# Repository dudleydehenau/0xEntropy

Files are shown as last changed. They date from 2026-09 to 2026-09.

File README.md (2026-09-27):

<h1 align="center">0xEntropy</h1>

<p align="center">
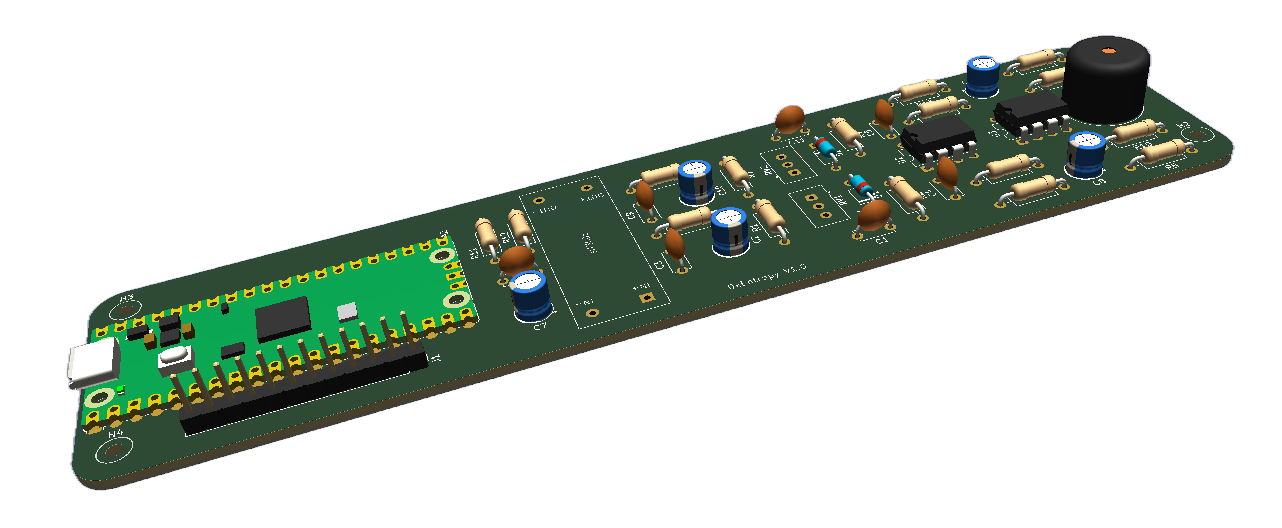
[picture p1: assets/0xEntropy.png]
PCB 3D Render
  
</p>

<p align="center">
  <em>Compact, open-source, USB-powered True Random Number Generator (TRNG) based on Zener diode avalanche breakdown noise and powered by an RP2040.</em>
</p>

---

## Overview

**0xEntropy** is a standalone hardware entropy generator. It harnesses the physical phenomenon of avalanche breakdown in a Zener diode to capture non-deterministic quantum noise, amplifies it, digitizes it at high speed using the Raspberry Pi Pico PIO state machines, and applies real-time SHA-256 cryptographic whitening.

The system features an onboard touchscreen interface, continuous health monitoring, and streams random data over USB.

---

## Features

- **Pure Physical Source**: Avalanche breakdown noise from a reverse-biased 12V Zener diode, filtered and amplified (MCP6002).
- **Filtered Virtual Ground ($V_{REF} = 2.5\text{V}$)**: Strict isolation against USB power rail noise and ripples.
- **Hardware Sampling (PIO)**: High-speed, jitter-free capture offloaded from the CPU.
- **Dual-Core Architecture (RP2040)**:
  - **Core 0**: Touchscreen LCD interface (ultra-lightweight 1-bit bitmap rendering engine), statistics processing, and alerts.
  - **Core 1**: Raw bit acquisition, real-time statistical health tests, and SHA-256 post-processing.
- **Live Monitoring**: Real-time Shannon entropy calculation and physical source health supervision.
- **100% Plug & Play**: Powered and queried via a standard USB port.

---

## Hardware & Schematics (KiCad)

The PCB isolates the sensitive analog front-end (Zener, op-amp, comparator) from the digital domain (RP2040, screen).

### Schematic
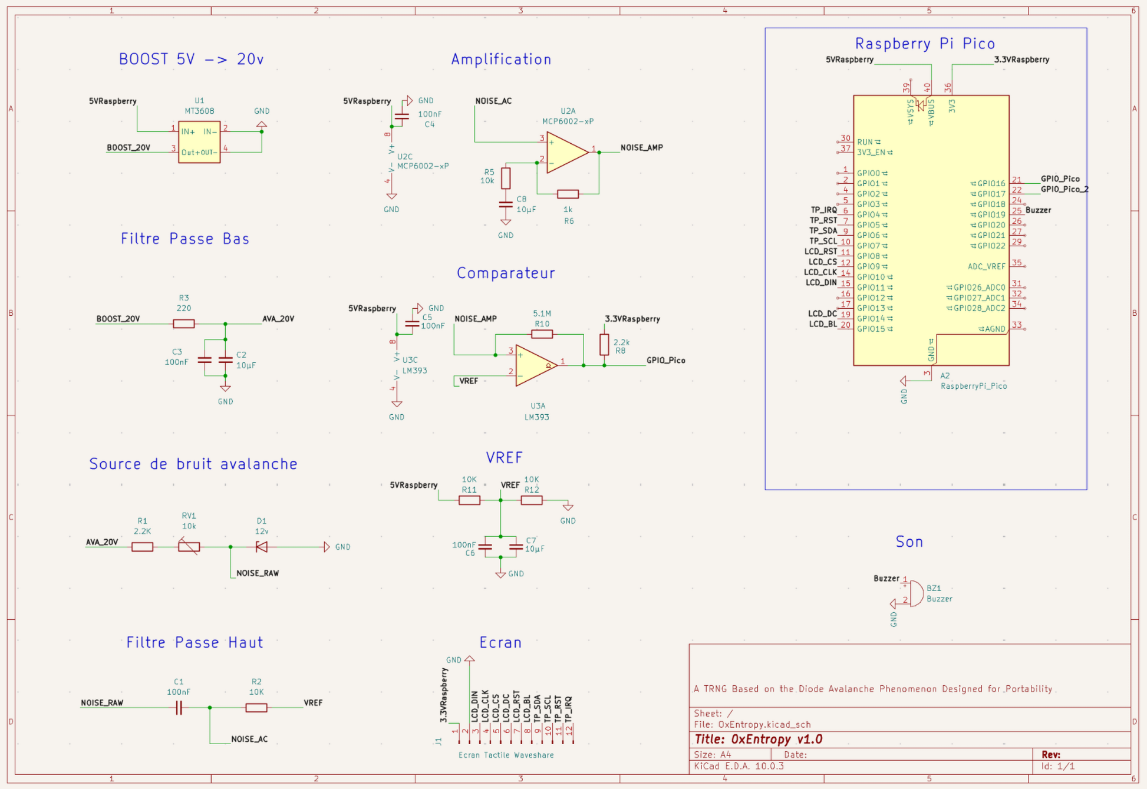
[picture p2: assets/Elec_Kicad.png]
KiCad Schematic


### PCB Layout
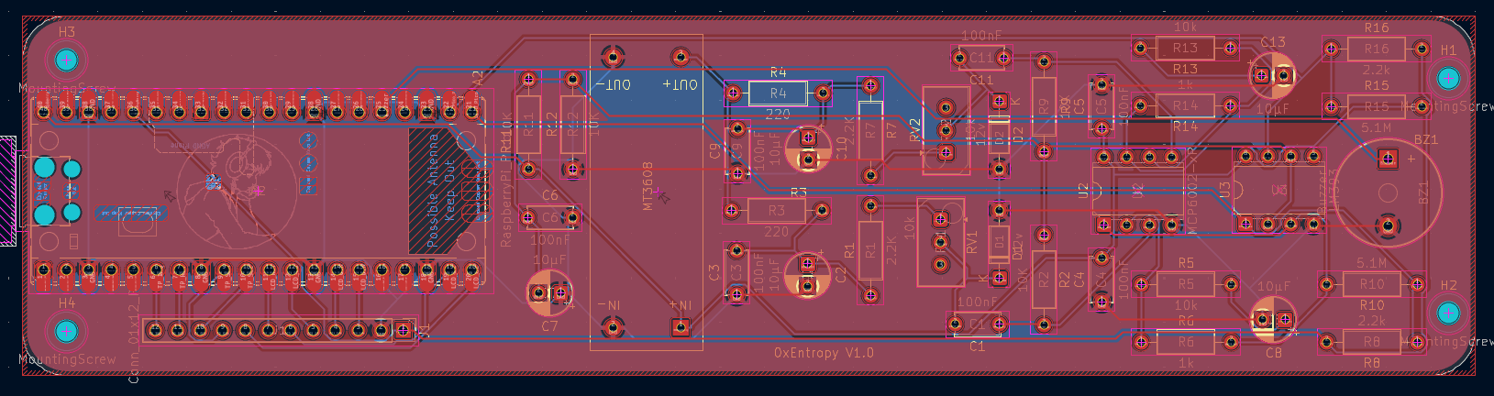
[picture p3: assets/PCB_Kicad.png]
KiCad PCB Routing


---

## Enclosure & 3D Design

A custom 3D enclosure was designed to house the main board, the touchscreen display, and provide access to the micro-USB port.

<table>
  <tr>
    <th width="50%" align="center">3D Model</th>
    <th width="50%" align="center">Assembled Prototype</th>
  </tr>
  <tr>
    <td align="center">
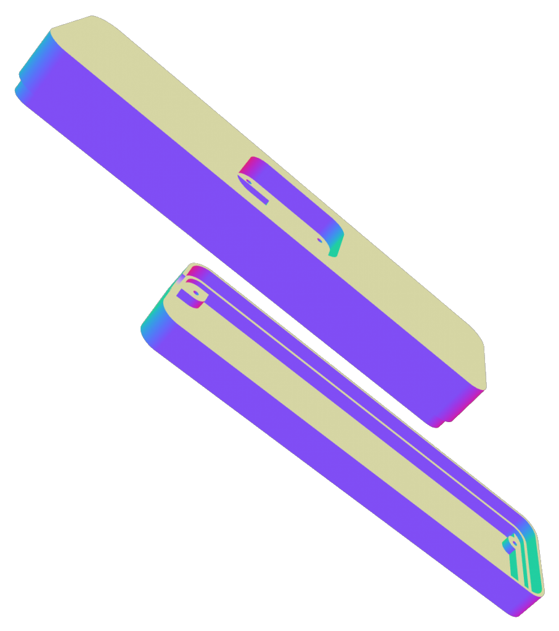
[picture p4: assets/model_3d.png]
3D Model
      
    </td>
    <td align="center">
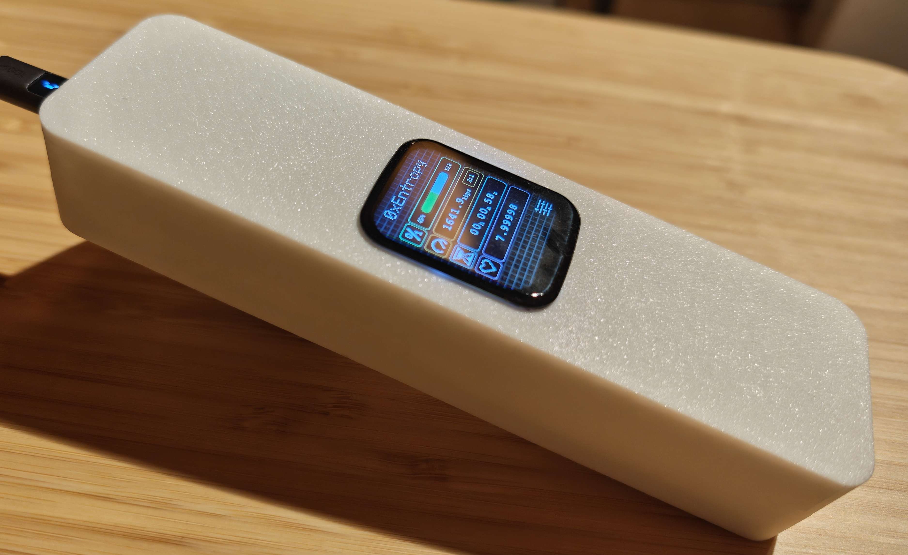
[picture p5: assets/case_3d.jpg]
Enclosure Photo
      
    </td>
  </tr>
</table>

<p align="center">
  3D Printing Timelapse
  <br>
  <em>Enclosure 3D printing timelapse</em>
</p>

*(F3D / STEP source files are available in the `/file3D` directory)*

---

## Firmware Structure

The firmware is written in **C/C++** using the Pico SDK:

- `firmware/0xEntropy.c`: Main entry point, orchestration, and core loop.
- `firmware/Entropy/`: Physical signal sampling and entropy generation routines.
- `firmware/Health/`: Continuous health monitoring (failure detection and drift detection).
- `firmware/Stats/`: Real-time statistical computations on bitstreams.
- `firmware/UI/`: Display drivers and user interface logic.

<p align="center">
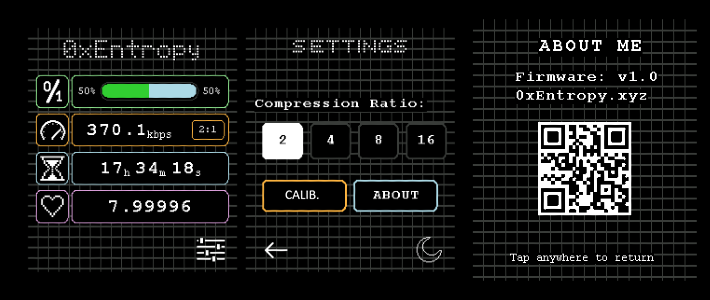
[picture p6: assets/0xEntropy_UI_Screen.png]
UI Screen
  
  <br>
  <em>Simulated values</em>
</p>

---

## Full Prototype Overview

Overall view of the assembled hardware: the operational PCB connected to the touchscreen display.

<p align="center">
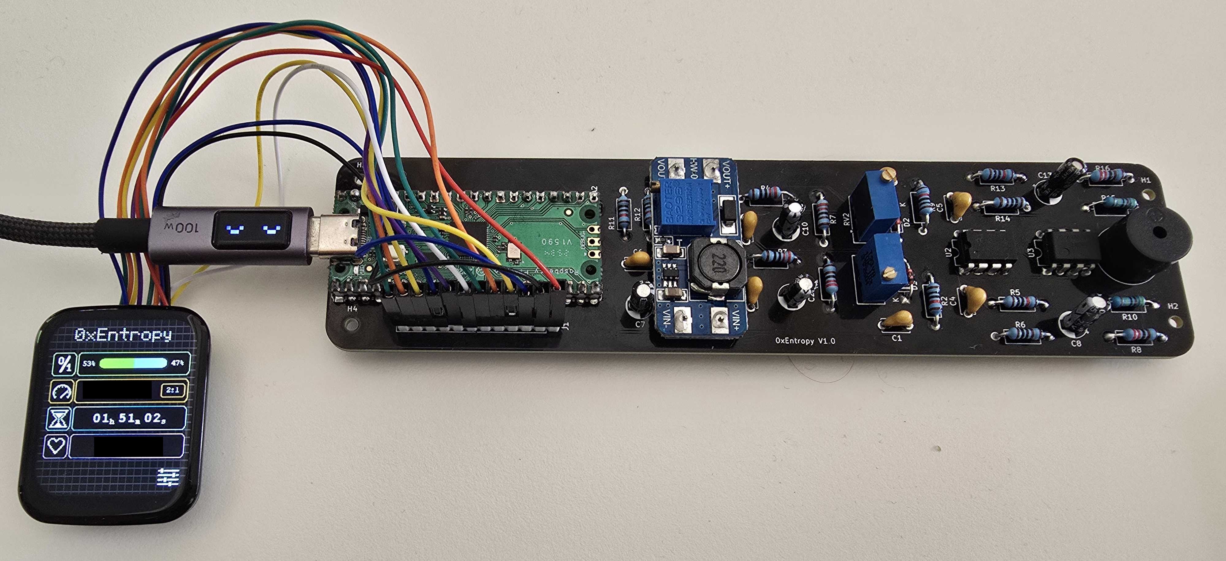
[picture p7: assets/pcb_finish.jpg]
Complete 0xEntropy Prototype
  
  <br>
  <em>Final 0xEntropy board assembled and connected to its touchscreen display</em>
</p>

---

## Quick Start

### 1. Flash the RP2040
1. Download the latest `0xEntropy.uf2` binary from the [Releases](../../releases).
2. Hold down the **BOOTSEL** button on the Raspberry Pi Pico and plug it into your computer via USB.
3. Drag and drop the `.uf2` file onto the mounted USB storage volume.

### 2. Stream Random Bytes

The Pico emulates a standard USB CDC serial port.

#### Option A: Using the Python Script (Recommended / Cross-platform)
Handles real-time throughput monitoring, automatic resume on disconnect, and works on Windows, Linux, and macOS:

```bash
# Dependency
pip install pyserial

# Stream data (e.g., capture 100 MB)
python collect.py -p COM4 -s 100000000 -o random.bin
```

#### Option B: Direct Command Line (Linux / macOS)
```bash
# Quick capture of 1 MB
head -c 1M /dev/ttyACM0 > random.bin
```

---

### 3. Verify Entropy Quality

Quick distribution analysis using the standard `ent` tool:

```bash
ent random.bin
```

Comprehensive statistical test battery with **Dieharder**:

```bash
# Run the full test suite (-a) on a binary stream (-g 201)
dieharder -a -g 201 -f random.bin
```

---

## Performance & Validation

The generator has been rigorously tested and validated for statistical randomness at scale.

- **Observed Throughput**: **~1,300 kbps** (~162 KB/s) continuous stream over USB CDC.
- **Post-Processing**: SHA-256 cryptographic whitening. Default 2:1 compression ratio (512:256 bits), user-selectable on-screen (4:1, 8:1, 16:1).

---

### 1. `ent` Test (10 GB Dataset)

Raw distribution analysis performed on a continuous **10 GB** dataset (`10,000,000,000 bytes`):

```text
Entropy = 8.000000 bits per byte.

Optimum compression would reduce the size
of this 10000000000 byte file by 0 percent.

Chi square distribution for 10000000000 samples is 279.96, and randomly
would exceed this value 13.56 percent of the times.

Arithmetic mean value of data bytes is 127.5013 (127.5 = random).
Monte Carlo value for Pi is 3.141522385 (error 0.00 percent).
Serial correlation coefficient is -0.000013 (totally uncorrelated = 0.0).
```

---

### 2. Dieharder Test Suite (10 GB Dataset)

Full results from the **Dieharder v3.31.1** test battery executed against a **10 GB** stream (SHA-256 2:1 ratio):

<details>

<summary><b>Click to view all 86 detailed test results (Dieharder)</b></summary>

| Test Name | ntuple | tsamples | psamples | p-value | Assessment |
| :--- | :---: | :---: | :---: | :---: | :---: |
| `diehard_birthdays` | 0 | 100 | 100 | 0.39466437 | **PASSED** |
| `diehard_operm5` | 0 | 1 000 000 | 100 | 0.07592355 | **PASSED** |
| `diehard_rank_32x32` | 0 | 40 000 | 100 | 0.59062810 | **PASSED** |
| `diehard_rank_6x8` | 0 | 100 000 | 100 | 0.95475163 | **PASSED** |
| `diehard_bitstream` | 0 | 2 097 152 | 100 | 0.40506079 | **PASSED** |
| `diehard_opso` | 0 | 2 097 152 | 100 | 0.88837531 | **PASSED** |
| `diehard_oqso` | 0 | 2 097 152 | 100 | 0.69125958 | **PASSED** |
| `diehard_dna` | 0 | 2 097 152 | 100 | 0.69906629 | **PASSED** |
| `diehard_count_1s_str` | 0 | 256 000 | 100 | 0.39737472 | **PASSED** |
| `diehard_count_1s_byt` | 0 | 256 000 | 100 | 0.92060347 | **PASSED** |
| `diehard_parking_lot` | 0 | 12 000 | 100 | 0.43926798 | **PASSED** |
| `diehard_2dsphere` | 2 | 8 000 | 100 | 0.92344609 | **PASSED** |
| `diehard_3dsphere` | 3 | 4 000 | 100 | 0.96173291 | **PASSED** |
| `diehard_squeeze` | 0 | 100 000 | 100 | 0.79221232 | **PASSED** |
| `diehard_sums` | 0 | 100 | 100 | 0.55542507 | **PASSED** |
| `diehard_runs` | 0 | 100 000 | 100 | 0.13786658 | **PASSED** |
| `diehard_runs` | 0 | 100 000 | 100 | 0.17085449 | **PASSED** |
| `diehard_craps` | 0 | 200 000 | 100 | 0.67687026 | **PASSED** |
| `diehard_craps` | 0 | 200 000 | 100 | 0.91082777 | **PASSED** |
| `marsaglia_tsang_gcd` | 0 | 10 000 000 | 100 | 0.93839213 | **PASSED** |
| `marsaglia_tsang_gcd` | 0 | 10 000 000 | 100 | 0.84764647 | **PASSED** |
| `sts_monobit` | 1 | 100 000 | 100 | 0.28551441 | **PASSED** |
| `sts_runs` | 2 | 100 000 | 100 | 0.29973049 | **PASSED** |
| `sts_serial` | 1 | 100 000 | 100 | 0.45563392 | **PASSED** |
| `sts_serial` | 2 | 100 000 | 100 | 0.14689616 | **PASSED** |
| `sts_serial` | 3 | 100 000 | 100 | 0.16976266 | **PASSED** |
| `sts_serial` | 3 | 100 000 | 100 | 0.58643956 | **PASSED** |
| `sts_serial` | 4 | 100 000 | 100 | 0.62041623 | **PASSED** |
| `sts_serial` | 4 | 100 000 | 100 | 0.93374301 | **PASSED** |
| `sts_serial` | 5 | 100 000 | 100 | 0.42325503 | **PASSED** |
| `sts_serial` | 5 | 100 000 | 100 | 0.96197560 | **PASSED** |
| `sts_serial` | 6 | 100 000 | 100 | 0.21788455 | **PASSED** |
| `sts_serial` | 6 | 100 000 | 100 | 0.69535327 | **PASSED** |
| `sts_serial` | 7 | 100 000 | 100 | 0.03066406 | **PASSED** |
| `sts_serial` | 7 | 100 000 | 100 | 0.01328619 | **PASSED** |
| `sts_serial` | 8 | 100 000 | 100 | 0.62365992 | **PASSED** |
| `sts_serial` | 8 | 100 000 | 100 | 0.28004021 | **PASSED** |
| `sts_serial` | 9 | 100 000 | 100 | 0.90096448 | **PASSED** |
| `sts_serial` | 9 | 100 000 | 100 | 0.97761790 | **PASSED** |
| `sts_serial` | 10 | 100 000 | 100 | 0.51356615 | **PASSED** |
| `sts_serial` | 10 | 100 000 | 100 | 0.64523823 | **PASSED** |
| `sts_serial` | 11 | 100 000 | 100 | 0.93859732 | **PASSED** |
| `sts_serial` | 11 | 100 000 | 100 | 0.32514183 | **PASSED** |
| `sts_serial` | 12 | 100 000 | 100 | 0.19453278 | **PASSED** |
| `sts_serial` | 12 | 100 000 | 100 | 0.35736285 | **PASSED** |
| `sts_serial` | 13 | 100 000 | 100 | 0.41024144 | **PASSED** |
| `sts_serial` | 13 | 100 000 | 100 | 0.52009147 | **PASSED** |
| `sts_serial` | 14 | 100 000 | 100 | 0.63356596 | **PASSED** |
| `sts_serial` | 14 | 100 000 | 100 | 0.05597814 | **PASSED** |
| `sts_serial` | 15 | 100 000 | 100 | 0.44014124 | **PASSED** |
| `sts_serial` | 15 | 100 000 | 100 | 0.17108281 | **PASSED** |
| `sts_serial` | 16 | 100 000 | 100 | 0.83506756 | **PASSED** |
| `sts_serial` | 16 | 100 000 | 100 | 0.92781694 | **PASSED** |
| `rgb_bitdist` | 1 | 100 000 | 100 | 0.50215495 | **PASSED** |
| `rgb_bitdist` | 2 | 100 000 | 100 | 0.67467770 | **PASSED** |
| `rgb_bitdist` | 3 | 100 000 | 100 | 0.68604339 | **PASSED** |
| `rgb_bitdist` | 4 | 100 000 | 100 | 0.63639093 | **PASSED** |
| `rgb_bitdist` | 5 | 100 000 | 100 | 0.00711522 | **PASSED** |
| `rgb_bitdist` | 6 | 100 000 | 100 | 0.03642615 | **PASSED** |
| `rgb_bitdist` | 7 | 100 000 | 100 | 0.54886931 | **PASSED** |
| `rgb_bitdist` | 8 | 100 000 | 100 | 0.94844778 | **PASSED** |
| `rgb_bitdist` | 9 | 100 000 | 100 | 0.80804374 | **PASSED** |
| `rgb_bitdist` | 10 | 100 000 | 100 | 0.76694934 | **PASSED** |
| `rgb_bitdist` | 11 | 100 000 | 100 | 0.55405954 | **PASSED** |
| `rgb_bitdist` | 12 | 100 000 | 100 | 0.79849495 | **PASSED** |
| `rgb_minimum_distance` | 2 | 10 000 | 1000 | 0.38755637 | **PASSED** |
| `rgb_minimum_distance` | 3 | 10 000 | 1000 | 0.93853771 | **PASSED** |
| `rgb_minimum_distance` | 4 | 10 000 | 1000 | 0.63970846 | **PASSED** |
| `rgb_minimum_distance` | 5 | 10 000 | 1000 | 0.33087978 | **PASSED** |
| `rgb_permutations` | 2 | 100 000 | 100 | 0.80472843 | **PASSED** |
| `rgb_permutations` | 3 | 100 000 | 100 | 0.80939095 | **PASSED** |
| `rgb_permutations` | 4 | 100 000 | 100 | 0.64196966 | **PASSED** |
| `rgb_permutations` | 5 | 100 000 | 100 | 0.97396760 | **PASSED** |
| `rgb_lagged_sum` | 0 | 1 000 000 | 100 | 0.29546209 | **PASSED** |
| `rgb_lagged_sum` | 1 | 1 000 000 | 100 | 0.10736047 | **PASSED** |
| `rgb_lagged_sum` | 2 | 1 000 000 | 100 | 0.90786168 | **PASSED** |
| `rgb_lagged_sum` | 3 | 1 000 000 | 100 | 0.03800803 | **PASSED** |
| `rgb_lagged_sum` | 4 | 1 000 000 | 100 | 0.69745767 | **PASSED** |
| `rgb_lagged_sum` | 5 | 1 000 000 | 100 | 0.30052203 | **PASSED** |
| `rgb_lagged_sum` | 6 | 1 000 000 | 100 | 0.81286624 | **PASSED** |
| `rgb_lagged_sum` | 7 | 1 000 000 | 100 | 0.79490517 | **PASSED** |
| `rgb_lagged_sum` | 8 | 1 000 000 | 100 | 0.85376675 | **PASSED** |
| `rgb_lagged_sum` | 9 | 1 000 000 | 100 | 0.46383055 | **PASSED** |
| `rgb_lagged_sum` | 10 | 1 000 000 | 100 | 0.63063661 | **PASSED** |
| `rgb_lagged_sum` | 11 | 1 000 000 | 100 | 0.39341615 | **PASSED** |
| `rgb_lagged_sum` | 12 | 1 000 000 | 100 | 0.21353291 | **PASSED** |
| `rgb_lagged_sum` | 13 | 1 000 000 | 100 | 0.73964502 | **PASSED** |
| `rgb_lagged_sum` | 14 | 1 000 000 | 100 | 0.76922594 | **PASSED** |
| `rgb_lagged_sum` | 15 | 1 000 000 | 100 | 0.55600967 | **PASSED** |
| `rgb_lagged_sum` | 16 | 1 000 000 | 100 | 0.59271918 | **PASSED** |
| `rgb_lagged_sum` | 17 | 1 000 000 | 100 | 0.90342589 | **PASSED** |
| `rgb_lagged_sum` | 18 | 1 000 000 | 100 | 0.59641374 | **PASSED** |
| `rgb_lagged_sum` | 19 | 1 000 000 | 100 | 0.59765640 | **PASSED** |
| `rgb_lagged_sum` | 20 | 1 000 000 | 100 | 0.52991615 | **PASSED** |
| `rgb_lagged_sum` | 21 | 1 000 000 | 100 | 0.44300317 | **PASSED** |
| `rgb_lagged_sum` | 22 | 1 000 000 | 100 | 0.94796060 | **PASSED** |
| `rgb_lagged_sum` | 23 | 1 000 000 | 100 | 0.20987094 | **PASSED** |
| `rgb_lagged_sum` | 24 | 1 000 000 | 100 | 0.36604221 | **PASSED** |
| `rgb_lagged_sum` | 25 | 1 000 000 | 100 | 0.28560285 | **PASSED** |
| `rgb_lagged_sum` | 26 | 1 000 000 | 100 | 0.52958989 | **PASSED** |
| `rgb_lagged_sum` | 27 | 1 000 000 | 100 | 0.17134459 | **PASSED** |
| `rgb_lagged_sum` | 28 | 1 000 000 | 100 | 0.99634800 | *WEAK* |
| `rgb_lagged_sum` | 29 | 1 000 000 | 100 | 0.36655513 | **PASSED** |
| `rgb_lagged_sum` | 30 | 1 000 000 | 100 | 0.16353244 | **PASSED** |
| `rgb_lagged_sum` | 31 | 1 000 000 | 100 | 0.36323221 | **PASSED** |
| `rgb_lagged_sum` | 32 | 1 000 000 | 100 | 0.67537924 | **PASSED** |
| `rgb_kstest_test` | 0 | 10 000 | 1000 | 0.60363864 | **PASSED** |
| `dab_bytedistrib` | 0 | 51 200 000 | 1 | 0.70763534 | **PASSED** |
| `dab_dct` | 256 | 50 000 | 1 | 0.18425080 | **PASSED** |
| `dab_filltree` | 32 | 15 000 000 | 1 | 0.80178758 | **PASSED** |
| `dab_filltree` | 32 | 15 000 000 | 1 | 0.26571865 | **PASSED** |
| `dab_filltree2` | 0 | 5 000 000 | 1 | 0.69465598 | **PASSED** |
| `dab_filltree2` | 1 | 5 000 000 | 1 | 0.71074721 | **PASSED** |
| `dab_monobit2` | 12 | 65 000 000 | 1 | 0.57586976 | **PASSED** |

</details>

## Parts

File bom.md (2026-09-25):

# Bill of Materials (BOM) — OxEntropy

| Réf. Schéma | Qté | Valeur / Désignation | Fabricant | Réf. Fabricant / Commande | Empreinte / Package |
| :--- | :---: | :--- | :--- | :--- | :--- |
| **A2** | 1 | Raspberry Pi Pico | Raspberry Pi | Raspberry Pi Pico | Module Pico THT |
| **BZ1** | 1 | Buzzer 12x9.5 RM7.6 | — | Buzzer THT | Buzzer_12x9.5RM7.6 |
| **C1, C3–C6, C9, C11** | 7 | 100nF | — | Céramique multicouche | C_Disc_D5.0mm_P5.00mm |
| **C2, C7, C8, C10, C13** | 5 | 10µF | — | Électrolytique Radial | CP_Radial_D5.0mm_P2.50mm |
| **D1, D2** | 2 | Diode Zener 12V | Nexperia | BZX79-C12 | DO-35 (SOD27) THT |
| **J1** | 1 | Connecteur 1x12 broches | — | Pin Header 2.54mm | PinHeader_1x12_P2.54mm_Vertical |
| **R1, R7, R8, R16** | 4 | 2.2kΩ | — | Résistance traversante 1/4W | R_Axial_DIN0207_P10.16mm |
| **R2, R5, R9, R11–R13** | 6 | 10kΩ | — | Résistance traversante 1/4W | R_Axial_DIN0207_P10.16mm |
| **R3, R4** | 2 | 220Ω | — | Résistance traversante 1/4W | R_Axial_DIN0207_P10.16mm |
| **R6, R14** | 2 | 1kΩ | — | Résistance traversante 1/4W | R_Axial_DIN0207_P10.16mm |
| **R10, R15** | 2 | 5.1MΩ | — | Résistance traversante 1/4W | R_Axial_DIN0207_P10.16mm |
| **RV1, RV2** | 2 | Potentiomètre 10kΩ | Vishay | T93YA103K | Vishay T93YA Vertical |
| **U1** | 1 | MT3608 (Module Step-Up) | TECNOIOT / Generic | MT3608 | Module Perso:MT3608 |
| **U2** | 1 | MCP6002-E/P (Ampli Op) | Microchip | MCP6002-E/P | DIP-8 (W7.62mm) |
| **U3** | 1 | LM393P (Comparateur) | Texas Instruments | LM393P | DIP-8 (W7.62mm) |

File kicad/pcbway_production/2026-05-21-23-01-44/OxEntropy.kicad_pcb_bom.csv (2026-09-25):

Designator | Quantity | Value | Footprint | Package | MPN | DNP | Mount_Type | Description | KiLib_Generator
A2 | 1 | RaspberryPi_Pico | RaspberryPi_Pico_Common_Unspecified |  |  |  | tht | Versatile and inexpensive microcontroller module powered by RP2040 dual-core Arm Cortex-M0+ processor up to 133 MHz, 264kB SRAM, 2MB QSPI flash; also supports Raspberry Pi Pico 2
BZ1 | 1 | Buzzer | Buzzer_12x9.5RM7.6 |  |  |  | tht | Buzzer, polarized
C1, C11, C3, C4, C5, C6, C9 | 7 | 100nF | C_Disc_D5.0mm_W2.5mm_P5.00mm |  |  |  | tht | Unpolarized capacitor, small symbol | capacitor/THT/other
C10, C13, C2, C7, C8 | 5 | 10µF | CP_Radial_D5.0mm_P2.50mm |  |  |  | tht | Unpolarized capacitor, small symbol | capacitor/THT/other
D1, D2 | 2 | 12v | D_DO-35_SOD27_P7.62mm_Horizontal |  |  |  | tht | Zener diode | diode/THT
J1 | 1 | Conn_01x12_Pin | PinHeader_1x12_P2.54mm_Vertical |  |  |  | tht | Generic connector, single row, 01x12, script generated | connector/pin_header_socket
R1, R7 | 2 | 2.2K | R_Axial_DIN0207_L6.3mm_D2.5mm_P10.16mm_Horizontal |  |  |  | tht | Resistor | resistor/THT
R10, R15 | 2 | 5.1M | R_Axial_DIN0207_L6.3mm_D2.5mm_P10.16mm_Horizontal |  |  |  | tht | Resistor | resistor/THT
R11, R12, R2, R9 | 4 | 10K | R_Axial_DIN0207_L6.3mm_D2.5mm_P10.16mm_Horizontal |  |  |  | tht | Resistor | resistor/THT
R13, R5 | 2 | 10k | R_Axial_DIN0207_L6.3mm_D2.5mm_P10.16mm_Horizontal |  |  |  | tht | Resistor | resistor/THT
R14, R6 | 2 | 1k | R_Axial_DIN0207_L6.3mm_D2.5mm_P10.16mm_Horizontal |  |  |  | tht | Resistor | resistor/THT
R16, R8 | 2 | 2.2k | R_Axial_DIN0207_L6.3mm_D2.5mm_P10.16mm_Horizontal |  |  |  | tht | Resistor | resistor/THT
R3, R4 | 2 | 220 | R_Axial_DIN0207_L6.3mm_D2.5mm_P10.16mm_Horizontal |  |  |  | tht | Resistor | resistor/THT
RV1, RV2 | 2 | 10k | Potentiometer_Vishay_T93YA_Vertical |  |  |  | tht | Trimmable resistor (preset resistor)
U1 | 1 | MT3608 | MT3608 |  |  |  | smt | High Efficiency 1.2MHz 2A Step Up Converter, 2-24V Vin, 28V Vout, 4A current limit, 1.2MHz, SOT23-6
U2 | 1 | MCP6002-xP | DIP-8_W7.62mm |  |  |  | tht | 1MHz, Low-Power Op Amp, DIP-8 | package/DIP/legacy
U3 | 1 | LM393 | DIP-8_W7.62mm |  |  |  | tht | Low-Power, Low-Offset Voltage, Dual Comparators, DIP-8/SOIC-8/TO-99-8 | package/DIP/legacy

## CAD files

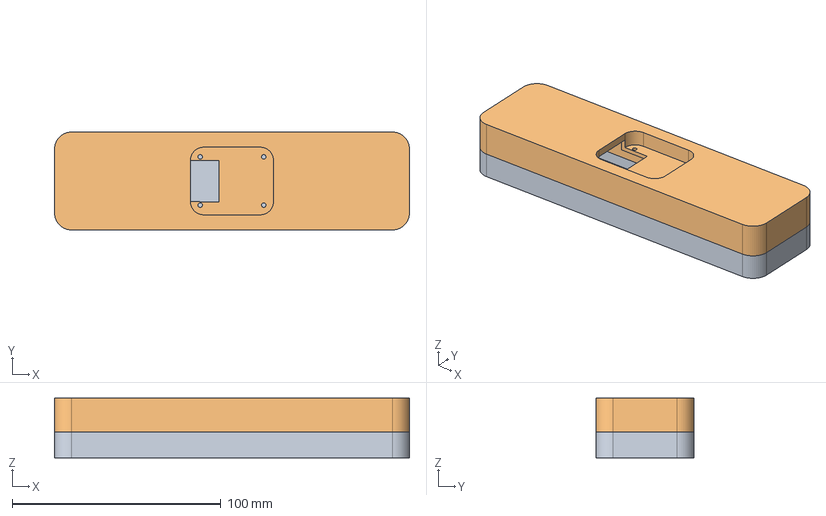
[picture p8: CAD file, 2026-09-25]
file3D/3D0xEntropyFinal.step
169.9 x 46.9 x 28.5 mm

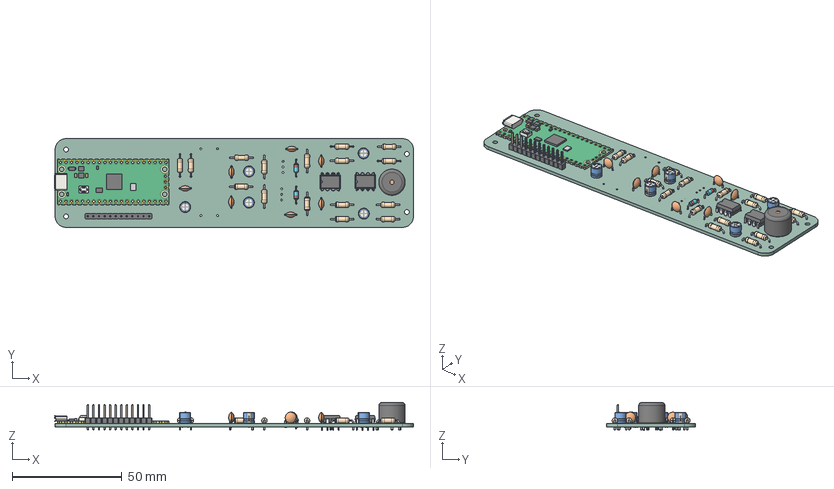
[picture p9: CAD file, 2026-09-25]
kicad/.step
163.8 x 40.5 x 12.8 mm
R_Axial_DIN0207_L63mm_D25mm_P1016mm_Horizontal x 16
CP_Radial_D50mm_P250mm x 5
DIP-8_W7.62mm x 2
RaspberryPi_Pico_Module_KiCad
C_Disc_D50mm_W25mm_P500mm x 7
PinHeader_1x12_P254mm_Vertical
D_DO-35_SOD27_P7.62mm_Horizontal x 2
Buzzer_12x95RM76
OxEntropy_PCB

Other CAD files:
file3D/3D0xEntropyFinal.f3d

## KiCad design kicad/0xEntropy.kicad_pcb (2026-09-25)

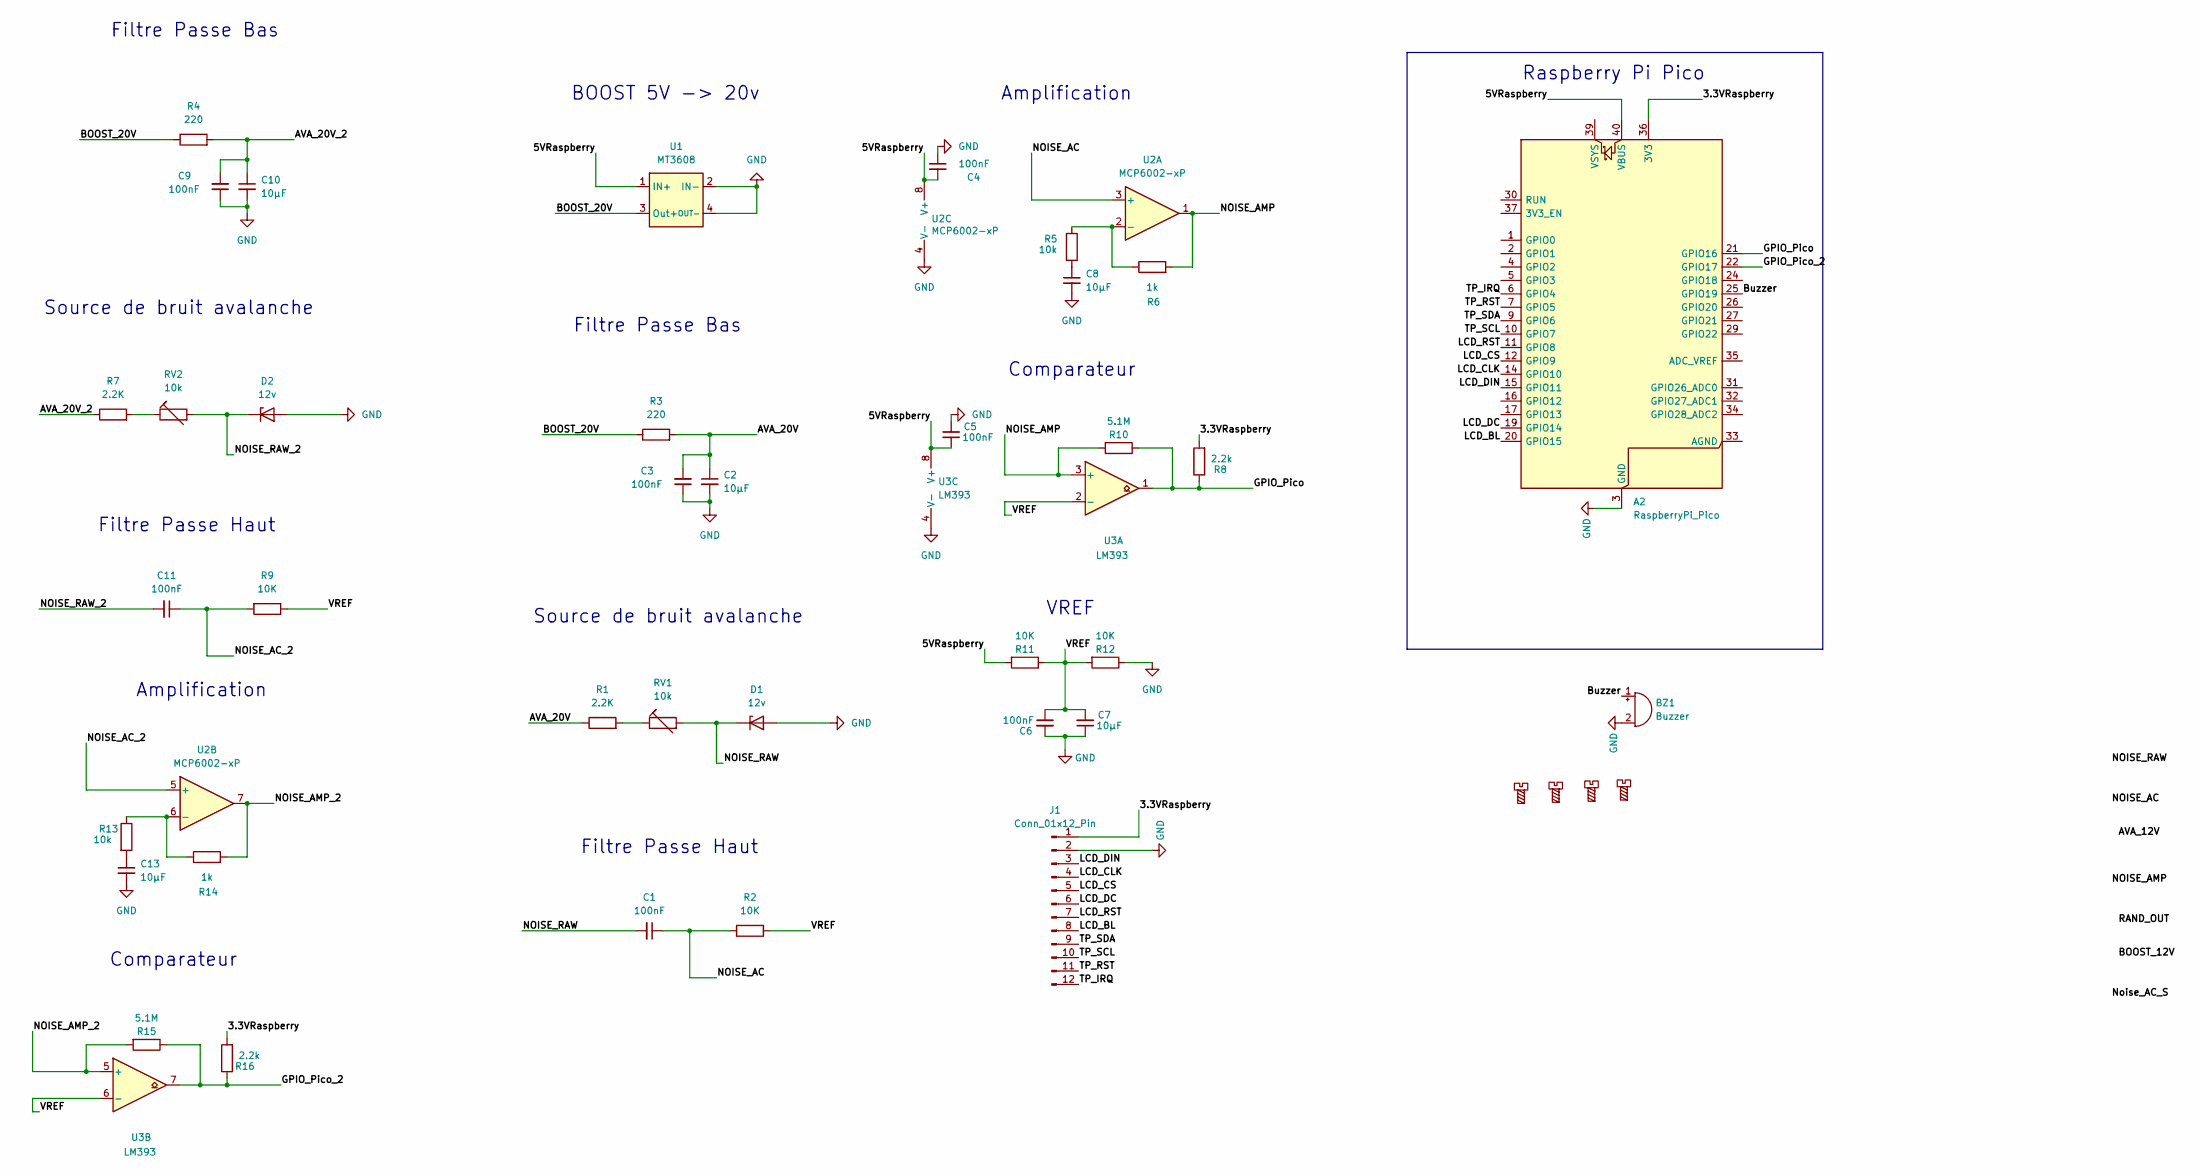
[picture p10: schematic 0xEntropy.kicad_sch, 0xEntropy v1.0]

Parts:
A2: RaspberryPi_Pico; RaspberryPi_Pico_Common_Unspecified
BZ1: Buzzer; Buzzer_12x9.5RM7.6
C1, C3, C4, C5, C6, C9, C11: 100nF; C_Disc_D5.0mm_W2.5mm_P5.00mm
C2, C7, C8, C10, C13: 10µF; CP_Radial_D5.0mm_P2.50mm
D1, D2: 12v; D_DO-35_SOD27_P7.62mm_Horizontal
H1, H2, H3, H4: MountingScrew; MountingHole_2.2mm_M2
J1: Conn_01x12_Pin; PinHeader_1x12_P2.54mm_Vertical
R1, R7: 2.2K; R_Axial_DIN0207_L6.3mm_D2.5mm_P10.16mm_Horizontal
R2, R9, R11, R12: 10K; R_Axial_DIN0207_L6.3mm_D2.5mm_P10.16mm_Horizontal
R3, R4: 220; R_Axial_DIN0207_L6.3mm_D2.5mm_P10.16mm_Horizontal
R5, R13: 10k; R_Axial_DIN0207_L6.3mm_D2.5mm_P10.16mm_Horizontal
R6, R14: 1k; R_Axial_DIN0207_L6.3mm_D2.5mm_P10.16mm_Horizontal
R8, R16: 2.2k; R_Axial_DIN0207_L6.3mm_D2.5mm_P10.16mm_Horizontal
R10, R15: 5.1M; R_Axial_DIN0207_L6.3mm_D2.5mm_P10.16mm_Horizontal
RV1, RV2: 10k; Potentiometer_Vishay_T93YA_Vertical
U1: MT3608
U2: MCP6002-xP; DIP-8_W7.62mm
U3: LM393; DIP-8_W7.62mm

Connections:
/3.3VRaspberry: A2.36 (3V3), J1.1, R8.2, R16.2
/5VRaspberry: A2.40 (VBUS), C4.2, C5.1, R11.2, U1.1 (IN+), U2.8 (V+), U3.8 (V+)
/AVA_20V: C2.1, C3.2, R1.1, R3.2
/AVA_20V_2: C9.2, C10.1, R4.2, R7.1
/BOOST_20V: R3.1, R4.1, U1.3 (Out+)
/Buzzer: A2.25 (GPIO19), BZ1.1 (+)
/GPIO_Pico: A2.21 (GPIO16), R8.1, R10.1, U3.1
/GPIO_Pico_2: A2.22 (GPIO17), R15.1, R16.1, U3.7
/LCD_BL: A2.20 (GPIO15), J1.8
/LCD_CLK: A2.14 (GPIO10), J1.4
/LCD_CS: A2.12 (GPIO9), J1.5
/LCD_DC: A2.19 (GPIO14), J1.6
/LCD_DIN: A2.15 (GPIO11), J1.3
/LCD_RST: A2.11 (GPIO8), J1.7
/NOISE_AC: C1.1, R2.2, U2.3 (+)
/NOISE_AC_2: C11.1, R9.2, U2.5 (+)
/NOISE_AMP: R6.2, R10.2, U2.1, U3.3 (+)
/NOISE_AMP_2: R14.2, R15.2, U2.7, U3.5 (+)
/NOISE_RAW: C1.2, D1.1 (K), RV1.2
/NOISE_RAW_2: C11.2, D2.1 (K), RV2.2
/TP_IRQ: A2.6 (GPIO4), J1.12
/TP_RST: A2.7 (GPIO5), J1.11
/TP_SCL: A2.10 (GPIO7), J1.10
/TP_SDA: A2.9 (GPIO6), J1.9
/VREF: C6.1, C7.2, R2.1, R9.1, R11.1, R12.2, U3.2 (-), U3.6 (-)
GND: A2.3 (GND), A2.8 (GND), A2.13 (GND), A2.18 (GND), A2.23 (GND), A2.28 (GND), A2.38 (GND), BZ1.2 (-), C2.2, C3.1, C4.1, C5.2, C6.2, C7.1, C8.2, C9.1, C10.2, C13.2, D1.2 (A), D2.2 (A), J1.2, R12.1, U1.2 (IN-), U1.4 (OUT-), U2.4 (V-), U3.4 (V-)
unnamed: C8.1, R5.2
unnamed: C13.1, R13.2
unnamed: R1.2, RV1.1
unnamed: R7.2, RV2.1
unnamed: R5.1, R6.1, U2.2 (-)
unnamed: R13.1, R14.1, U2.6 (-)

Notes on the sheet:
Amplification
Source de bruit avalanche
Filtre Passe Bas
Comparateur
Filtre Passe Haut
VREF
BOOST 5V -> 20v
Raspberry Pi Pico

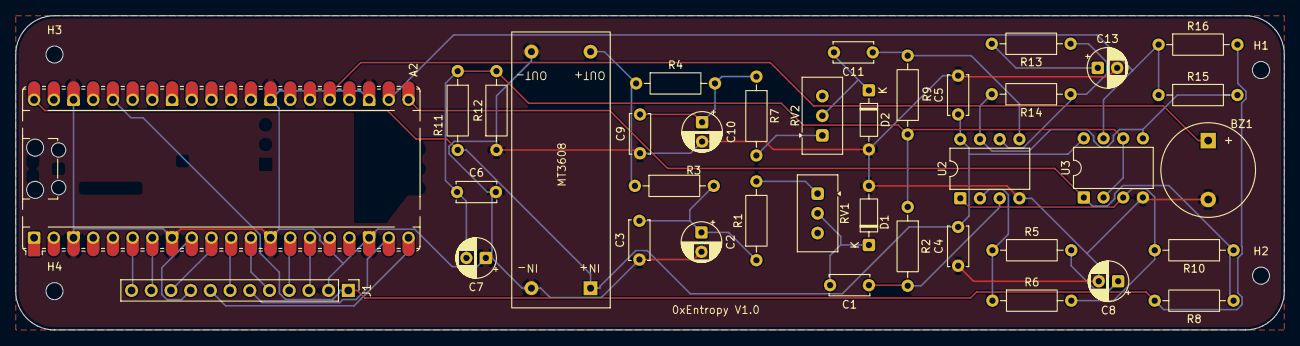
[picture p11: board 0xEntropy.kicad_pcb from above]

Board: 2 copper layers, 163.5 x 40.5 mm, 42 parts (0 on the bottom side), 32 nets.

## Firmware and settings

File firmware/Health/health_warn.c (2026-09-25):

#include "health_warn.h"

// faut que alerte_sante_trng soit bien declaree dans ce header sinon ca va planter
#include "Health/health_test.h"

// les trucs de base pour le pico (pwm, gpio, watchdog et compagnie)
#include "pico/stdlib.h"
#include "hardware/pwm.h"
#include "hardware/watchdog.h"
#include "hardware/gpio.h"

// drivers pour l'ecran waveshare et la gestion du tactile
#include "UI/Screen/Driver/DEV_Config.h"
#include "UI/Screen/Driver/LCD_1in69.h"
#include "UI/Screen/Driver/Touch_1in69.h"
#include "UI/Screen/Screen_app.h"

#define BUZZER_PIN 19

// un petit flag pour eviter que l'alarme se relance en boucle
bool alarme_declenchee = false;

// la fonction qui verifie si ca a pete et balance l'alerte
void Check_et_alerte(UWORD *image_buffer) {
    if (alerte_sante_trng && !alarme_declenchee) {
        alarme_declenchee = true;

        // on met la luminosite a fond
        DEV_SET_PWM(100); 

        // on dessine l'ecran de la mort en rouge si le buffer est pret
        if (image_buffer != NULL) {
            dessiner_page_fatal(image_buffer);
            LCD_1IN69_Display(image_buffer); 
        }

        // on configure le buzzer pour qu'il siffle a environ 1.25 khz
        gpio_set_function(BUZZER_PIN, GPIO_FUNC_PWM);
        uint slice_num = pwm_gpio_to_slice_num(BUZZER_PIN);
        pwm_set_clkdiv(slice_num, 10.0f); 
        pwm_set_wrap(slice_num, 10000); 
        pwm_set_chan_level(slice_num, pwm_gpio_to_channel(BUZZER_PIN), 5000); 
        pwm_set_enabled(slice_num, true);

        bool son_active = true;

        // boucle infinie pour bloquer le systeme et attendre un appui tactile
        while(true) {
            watchdog_update(); // on oublie pas de nourrir le chien pour eviter le reboot

            if (son_active) {
                // on regarde si quelqu'un touche l'ecran
                if (DEV_Digital_Read(DEV_I2C_INT) == 0) {
                    Touch_1IN69_XY struct_tc = Touch_1IN69_Get_Point();
                    if (struct_tc.x_point != 0 && struct_tc.y_point != 0) {

                        // tactile detecte : on coupe le pwm
                        pwm_set_enabled(slice_num, false);

                        // on remet la pin en sortie normale a 0 pour etre sur que ca se taise
                        gpio_set_function(BUZZER_PIN, GPIO_FUNC_SIO);
                        gpio_set_dir(BUZZER_PIN, GPIO_OUT);
                        gpio_put(BUZZER_PIN, 0);

                        son_active = false;
                    }
                }
            }
            sleep_ms(100); // petite pause pour pas faire chauffer le processeur
        }
    }
}

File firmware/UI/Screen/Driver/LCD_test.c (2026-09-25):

#include "pico/stdlib.h"
#include <stdio.h>
#include <stdlib.h> // Pour malloc et free
#include <stdint.h> // Pour uint32_t

#include "LCD_1in69.h"
#include "Touch_1in69.h"
#include "GUI_Paint.h"
#include "DEV_Config.h"

// On remplace 'int main()' par une fonction appelable
void run_lcd_test(void) {
    printf("Debut du test Ecran Tactile...\r\n");

    // 1. Initialisation du matériel (SPI, I2C, GPIO)
    if (DEV_Module_Init() != 0) {
        printf("Erreur d'initialisation materielle!\r\n");
        return; // On utilise return tout court au lieu de return -1 car c'est un 'void'
    }

    // 2. Initialisation de l'écran LCD
    LCD_1IN69_Init(HORIZONTAL);
    LCD_1IN69_Clear(WHITE);

    // Activer le rétroéclairage (à commenter si DEV_SET_PWM n'existe pas)
    DEV_SET_PWM(100); 

    // 3. Initialisation du Tactile (CST816T / CST816D)
    Touch_1IN69_init(0);

    // 4. Configuration de la zone de dessin (Paint)
    // CORRECTION ICI : uint32_t pour éviter le dépassement de mémoire (overflow)
    uint32_t Imagesize = (uint32_t)LCD_1IN69_HEIGHT * LCD_1IN69_WIDTH * 2;
    UWORD *BlackImage;
    if((BlackImage = (UWORD *)malloc(Imagesize)) == NULL) {
        printf("Erreur d'allocation memoire...\r\n");
        return;
    }

    Paint_NewImage((UBYTE *)BlackImage, LCD_1IN69_WIDTH, LCD_1IN69_HEIGHT, 0, WHITE);
    Paint_SetScale(65);
    Paint_Clear(WHITE);
    Paint_SetRotate(ROTATE_0);

    // Titre de base
    Paint_DrawString_EN(10, 10, "Test Tactile", &Font16, WHITE, BLACK);
    LCD_1IN69_Display(BlackImage);

    // 5. Boucle principale
    while (true) {
        // La broche IRQ (DEV_I2C_INT) passe à l'état bas quand on touche l'écran
        if (DEV_Digital_Read(DEV_I2C_INT) == 0) {

            // Lecture des coordonnées I2C
            Touch_1IN69_XY struct_tc;
            struct_tc.mode = 0;
            Touch_1IN69_Get_Point(&struct_tc);

            // Si les coordonnées sont valides
            if (struct_tc.x_point != 0 && struct_tc.y_point != 0) {
                // Effacer l'ancienne zone de texte (pour ne pas superposer)
                Paint_ClearWindows(10, 50, 240, 100, WHITE);

                // Préparer le texte des coordonnées
                char coord_str[32];
                sprintf(coord_str, "X: %03d Y: %03d", struct_tc.x_point, struct_tc.y_point);

                // Dessiner le texte sur l'image en mémoire
                Paint_DrawString_EN(10, 50, coord_str, &Font20, WHITE, BLUE);

                // Envoyer l'image à l'écran
                LCD_1IN69_DisplayWindows(10, 50, 240, 100, BlackImage);

                printf("Touche detectee -> X: %d, Y: %d\r\n", struct_tc.x_point, struct_tc.y_point);
            }
        }
        sleep_ms(20); // Petite pause pour ne pas saturer le bus I2C
    }

    free(BlackImage);
}
